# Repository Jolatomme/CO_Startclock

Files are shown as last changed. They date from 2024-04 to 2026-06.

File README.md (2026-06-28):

# Orienteering Start Clock synchronized to DCF77



Equity in sport is a key point during competition. In orienteering, equity is not guaranteed — start time differs per category and per racer. The start clock has no synchronization with the finish clock (managed by the punching system). Two unsynchronized clocks will drift and introduce uncertainty in effective race time. This project solves that problem by keeping the start clock synchronized to the absolute time delivered by the DCF77 signal.

More details on the [project Wiki](https://github.com/Jolatomme/CO_Startclock/wiki).

## Features

- Synchronizes to DCF77 time signal (German longwave, 77.5 kHz)
- Falls back to internal RTC when DCF77 signal is unavailable
- Real-time display on MAX7219 LED dot matrix (64x8)
- Automatic DST (summer/winter time) handling
- Built on MicroPython for rapid prototyping

## Hardware Requirements

| Component | Description |
|---|---|
| Microcontroller | STM32 Nucleo-64 board (see [supported boards](https://github.com/Jolatomme/CO_Startclock/wiki#micro-controller-platform)) |
| DCF77 receiver | Standard DCF77 module with antenna (e.g., DCF77-1, Hama, etc.) |
| Display | MAX7219-based 8x8 LED dot matrix, 8 modules chained (64x8) |
| Power | USB or external 5V supply |

## Pin Connections

| Nucleo Pin | Connection |
|---|---|
| D4 | DCF77 receiver TCO (time signal output) |
| D7 | MAX7219 CS (chip select) |
| SPI2 SCK | MAX7219 CLK |
| SPI2 MOSI | MAX7219 DIN |
| 3.3V / 5V | DCF77 receiver VCC |
| GND | Common ground |

## Getting Started

### 1. Install MicroPython

Download the latest MicroPython firmware for your board from [micropython.org](https://micropython.org/download/) and flash it using the STM32 Cube Programmer or DFU mode.

### 2. Upload the firmware

```bash
# Using ampy
ampy --port COM3 put boot.py
ampy --port COM3 put main.py
ampy --port COM3 put dcf77.py
ampy --port COM3 put max7219.py

# Or using rshell
rshell -p COM3 cp *.py /pyboard/
```

### 3. Wire the components

Refer to the [Fritzing layout](Fritzing/CO_Clock.fzz) or the [KiCad schematics](StartClock/StartClock.kicad_sch) for detailed wiring.

### 4. Power on

The clock will synchronize with DCF77 and display the current time. The onboard LED blinks once per second and stays on during the last 10 seconds of each minute.

## Project Structure

```
├── nucleo_flash/          # MicroPython firmware
│   ├── boot.py            # Boot configuration
│   ├── main.py            # Main application (async RTC + display)
│   ├── dcf77.py           # DCF77 signal decoder
│   ├── max7219.py         # MAX7219 LED matrix driver
│   └── ds18x20.py         # DS18X20 temperature sensor driver
├── StartClock/            # KiCad hardware design
│   ├── StartClock.kicad_sch   # Schematic
│   ├── StartClock.kicad_pcb   # PCB layout
│   └── StartClock.kicad_pro   # Project file
├── Fritzing/              # Breadboard layout
│   └── CO_Clock.fzz
├── Img/                   # Images
├── README.md
└── LICENSE                # MIT
```

## Project example on a single-sided stripboard

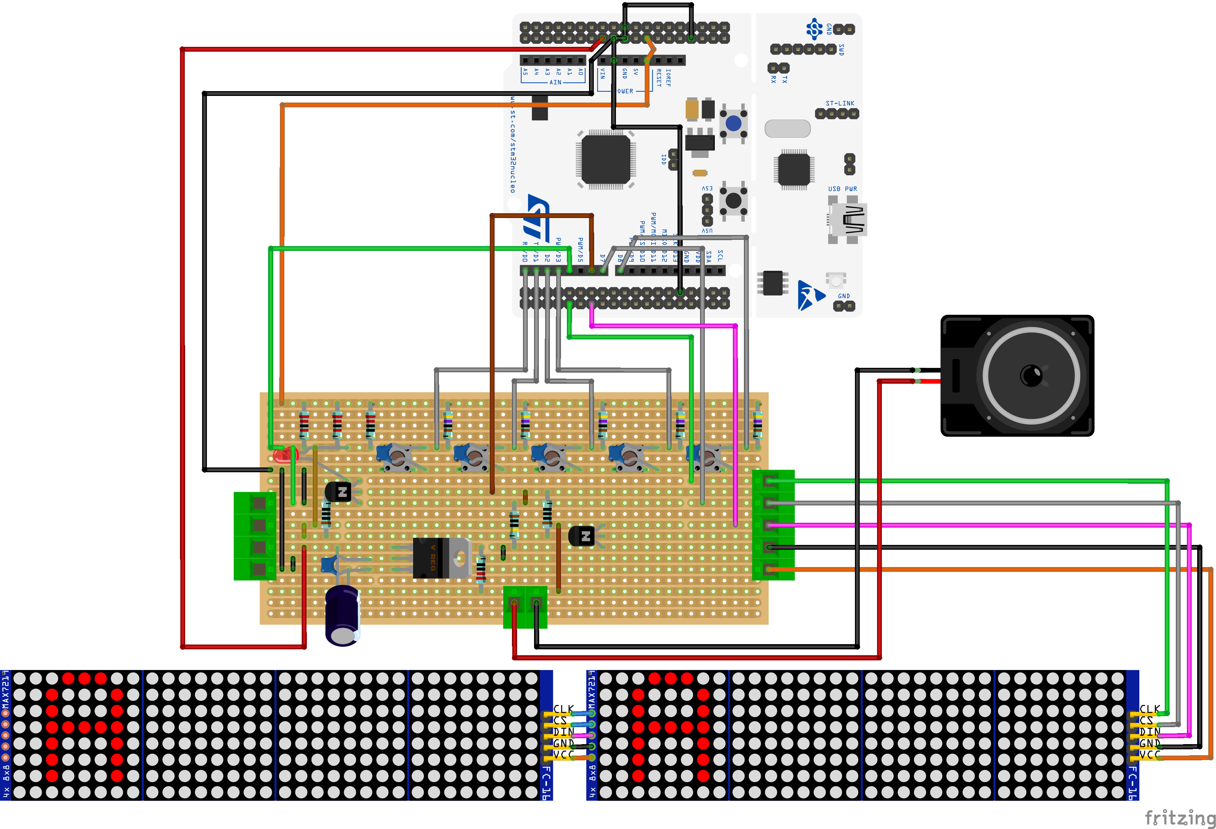
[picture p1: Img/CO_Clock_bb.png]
Realization


## License

This project is licensed under the [MIT License](LICENSE).

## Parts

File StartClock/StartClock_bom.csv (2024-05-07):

Reference | Value | Footprint | Qty | DNP | Ref mouser | Description
C1,C2,C3,C5,C6,C7,C11,C12 | 100n | Capacitor_SMD:C_0805_2012Metric_Pad1.18x1.45mm_HandSolder | 8 |  | https://www.mouser.fr/ProductDetail/KEMET/C0805C104K6RACTU?qs=NrXEK%2Fuukt5je6JkV2NA6Q%3D%3D | Unpolarized capacitor
C4,C13,C14 | 4.7u | Capacitor_SMD:C_0805_2012Metric_Pad1.18x1.45mm_HandSolder | 3 |  | https://www.mouser.fr/ProductDetail/Murata-Electronics/GRM21BZ7YA475KE15L?qs=Ey7%2FXF42M3dwsQijVSe80A%3D%3D | Unpolarized capacitor
C8 | 0.047u | Capacitor_SMD:C_0805_2012Metric_Pad1.18x1.45mm_HandSolder | 1 |  | https://www.mouser.fr/ProductDetail/KYOCERA-AVX/08053C473KAT4A?qs=OgzxwkGQ6NJ%2FkRAYg4QbYg%3D%3D | Unpolarized capacitor
C9 | 220u | Capacitor_THT:CP_Radial_D10.0mm_P5.00mm | 1 |  | None: in Stock | Polarized capacitor
C10 | 10u | Capacitor_SMD:C_0805_2012Metric_Pad1.18x1.45mm_HandSolder | 1 |  | https://www.mouser.fr/ProductDetail/Murata-Electronics/GRM21BZ71E106KE15K?qs=Ey7%2FXF42M3ceEkXCU194qQ%3D%3D | Unpolarized capacitor
D1 | LED | LED_SMD:LED_0805_2012Metric_Pad1.15x1.40mm_HandSolder | 1 |  | https://www.mouser.fr/ProductDetail/Wurth-Elektronik/150080SS75000?qs=LlUlMxKIyB2zzpiaOzrUdw%3D%3D | Light emitting diode
J1 | Screw_Terminal_01x05 | TerminalBlock_Phoenix:TerminalBlock_Phoenix_MPT-0,5-5-2.54_1x05_P2.54mm_Horizontal | 1 |  | https://www.mouser.fr/ProductDetail/Wurth-Elektronik/691210910005?qs=sPbYRqrBIVmsC84njkCQMg%3D%3D | Generic screw terminal, single row, 01x05, script generated (kicad-library-utils/schlib/autogen/connector/)
J2,J3,J4 | Screw_Terminal_01x02 | TerminalBlock_Phoenix:TerminalBlock_Phoenix_MPT-0,5-2-2.54_1x02_P2.54mm_Horizontal | 3 |  | https://www.mouser.fr/ProductDetail/Wurth-Elektronik/691210910002?qs=sPbYRqrBIVlpmUgpxfjjUA%3D%3D | Generic screw terminal, single row, 01x02, script generated (kicad-library-utils/schlib/autogen/connector/)
J5 | Screw_Terminal_01x04 | TerminalBlock_Phoenix:TerminalBlock_Phoenix_MPT-0,5-4-2.54_1x04_P2.54mm_Horizontal | 1 |  | https://www.mouser.fr/ProductDetail/Wurth-Elektronik/691210910004?qs=sPbYRqrBIVlxffWXw70IkA%3D%3D | Generic screw terminal, single row, 01x04, script generated (kicad-library-utils/schlib/autogen/connector/)
Q1,Q2 | 2STR1160 | Package_TO_SOT_SMD:TSOT-23 | 2 |  | None: in Stock | NPN transistor, base/emitter/collector
R1,R10 | 100 | Resistor_SMD:R_0805_2012Metric_Pad1.20x1.40mm_HandSolder | 2 |  | https://www.mouser.fr/ProductDetail/YAGEO/RT0805DRD07100RL?qs=%2Ff7pOCXLR5eK3aDJ3OLj3w%3D%3D | Resistor, US symbol
R2,R12 | 220 | -- valeurs mixtées -- | 2 |  | -- valeurs mixtées -- | Resistor, US symbol
R3,R9 | 22k | Resistor_SMD:R_0805_2012Metric_Pad1.20x1.40mm_HandSolder | 2 |  | https://www.mouser.fr/ProductDetail/YAGEO/RT0805FRE1322KL?qs=1mbolxNpo8eWV%252BfmE3nyzw%3D%3D | Resistor, US symbol
R4,R5,R6,R8,R11 | 4.7k | Resistor_SMD:R_0805_2012Metric_Pad1.20x1.40mm_HandSolder | 5 |  | https://www.mouser.fr/ProductDetail/YAGEO/RC0805FR-074K7L?qs=VLOqbHBAO5cYXbrd7RTmuQ%3D%3D | Resistor, US symbol
R7 | 1Meg | Resistor_SMD:R_0805_2012Metric_Pad1.20x1.40mm_HandSolder | 1 |  | https://www.mouser.fr/ProductDetail/YAGEO/RT0805FRE101ML?qs=F5EMLAvA7ICcBycWGMkoRg%3D%3D | Resistor, US symbol
R13 | 9.1k | Resistor_SMD:R_0805_2012Metric_Pad1.20x1.40mm_HandSolder | 1 |  | https://www.mouser.fr/ProductDetail/YAGEO/RT0805FRE079K1L?qs=yNCrj0CQcyLO9GcBQGw%2FWw%3D%3D | Resistor, US symbol
R14,R16 | 1.2k | Resistor_SMD:R_0805_2012Metric_Pad1.20x1.40mm_HandSolder | 2 |  | https://www.mouser.fr/ProductDetail/YAGEO/RT0805FRE071K2L?qs=Of9BA0M78V%2FOQKObZjZlOg%3D%3D | Resistor, US symbol
R15 | 10 | Resistor_SMD:R_0805_2012Metric_Pad1.20x1.40mm_HandSolder | 1 |  | https://www.mouser.fr/ProductDetail/YAGEO/RT0805FRE1310RL?qs=1mbolxNpo8cxANW8i7GXPg%3D%3D | Resistor, US symbol
SW1,SW2,SW3,SW4,SW6 | SW_Omron_B3FS | Button_Switch_SMD:SW_SPST_Omron_B3FS-101xP | 5 |  | https://www.mouser.fr/ProductDetail/Omron-Electronics/B3FS-1012P?qs=1tDaWCEHQQ7mwfTJVAKWQA%3D%3D | Omron B3FS 6x6mm single pole normally-open tactile switch
U1 | CO StartClock | Nucleo_64:ST_Morpho_Connector_64_NOHOLES_TOP | 1 |  | None: in Stock | Nucleo 64 Development Board with STM32L152RE
U2 | LM78M05_TO252 | Package_TO_SOT_SMD:TO-252-2 | 1 |  | https://www.mouser.fr/ProductDetail/STMicroelectronics/L7805CDT-TR?qs=gq%2F78KzUDX67VndS%2FbSB4Q%3D%3D | Positive 500mA 35V Linear Regulator, Fixed Output 5V, TO-252 (D-PAK)
U3 | LM386 | Package_SO:SOIC-8_3.9x4.9mm_P1.27mm | 1 |  | https://www.mouser.fr/ProductDetail/Texas-Instruments/LM386MX-1-NOPB?qs=QbsRYf82W3FIdJRa%252BlgeNQ%3D%3D | Low Voltage Audio Power Amplifier, DIP-8/SOIC-8/SSOP-8

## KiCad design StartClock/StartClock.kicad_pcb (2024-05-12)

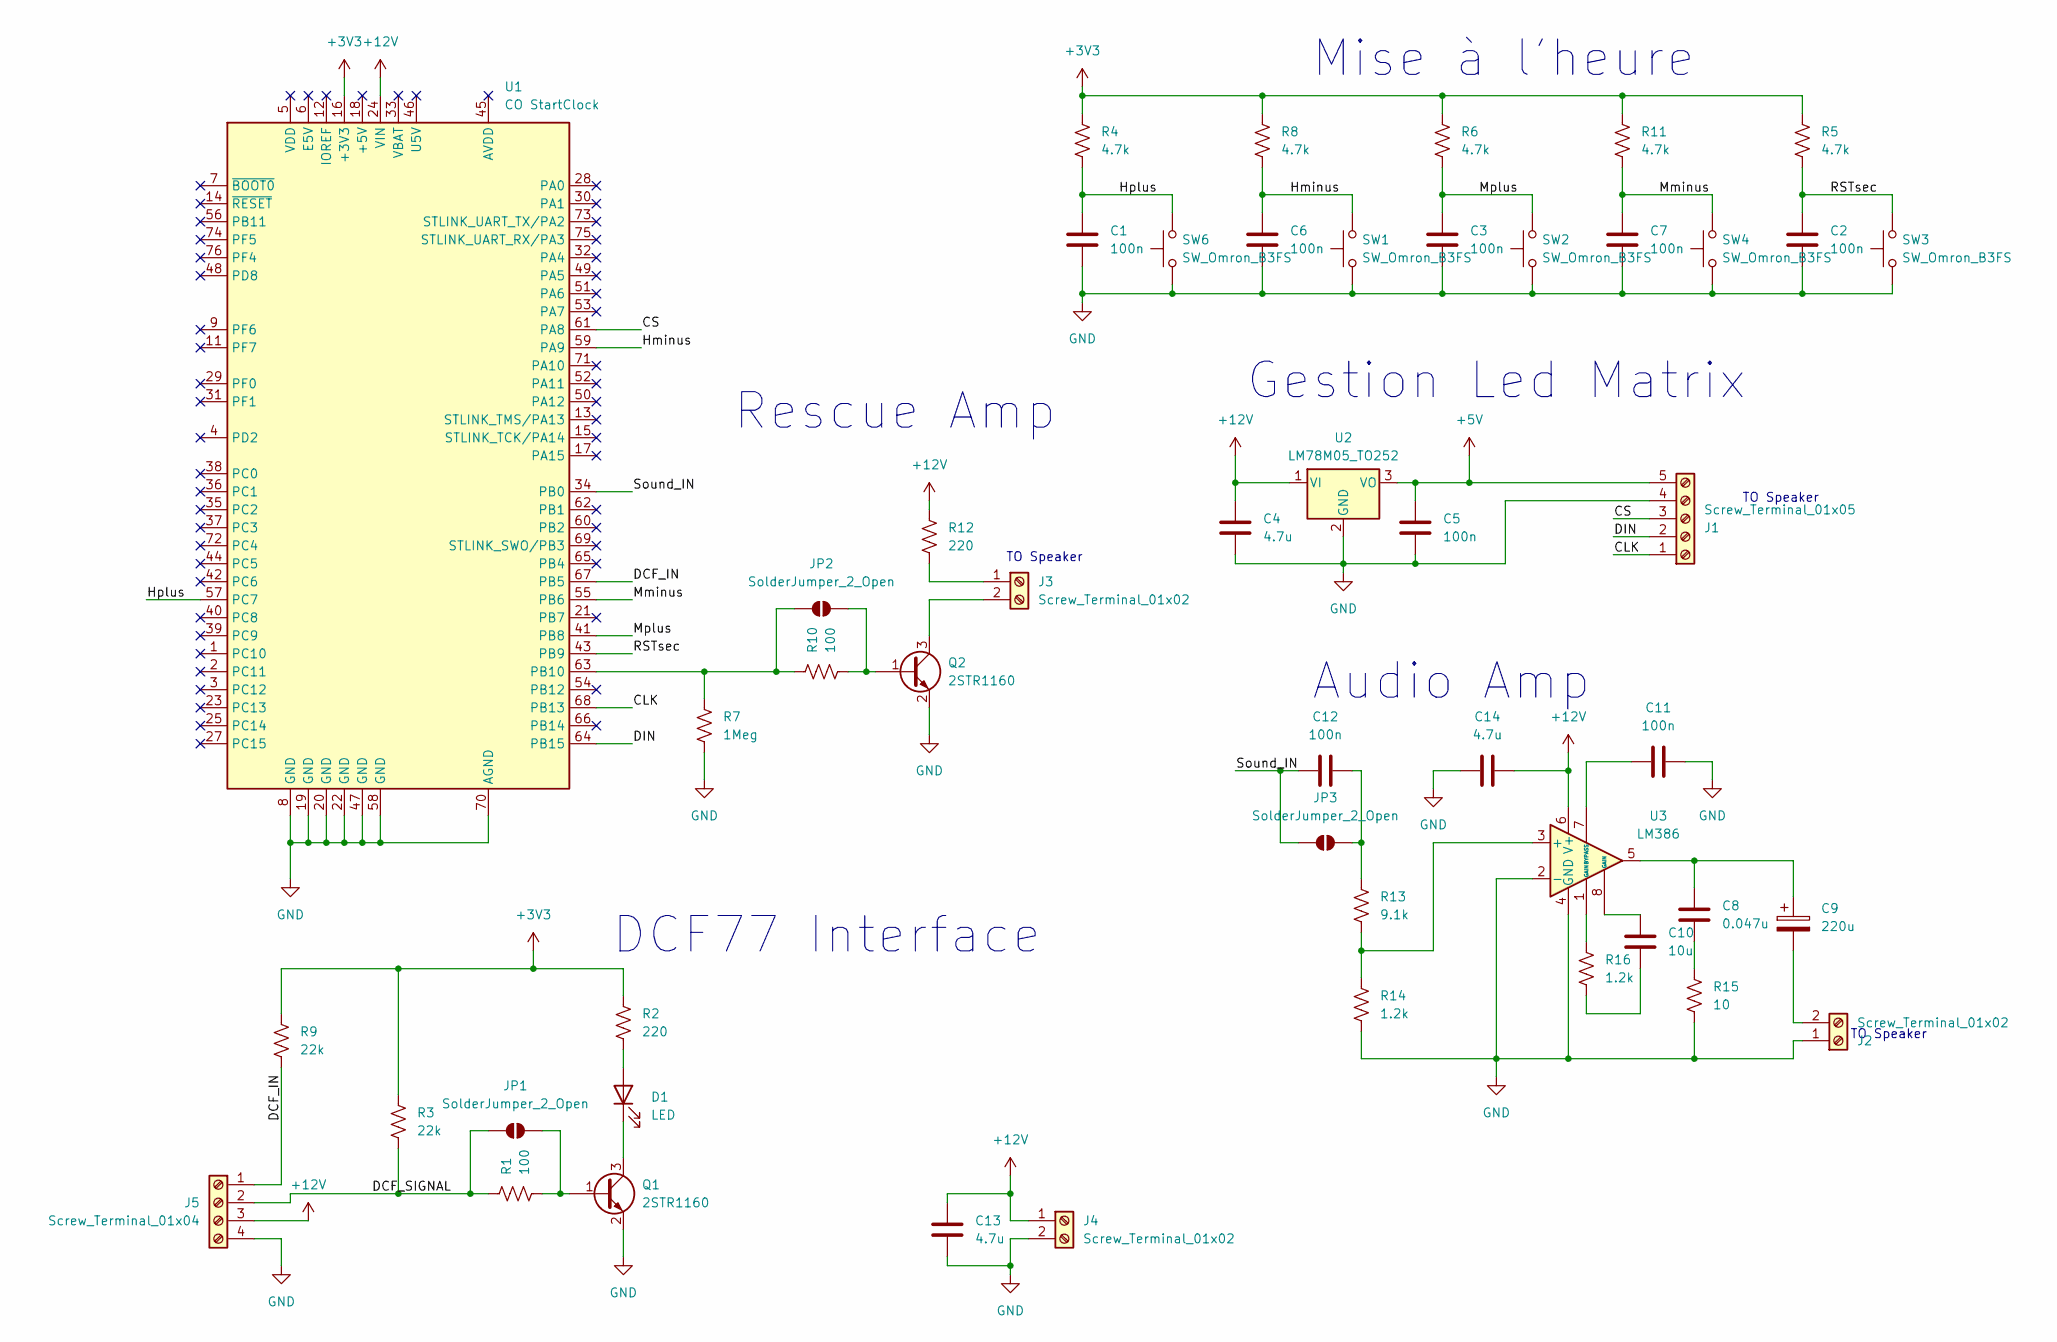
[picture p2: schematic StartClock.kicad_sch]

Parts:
C1, C2, C3, C5, C6, C7, C11, C12: 100n; C_0805_2012Metric_Pad1.18x1.45mm_HandSolder
C4, C13, C14: 4.7u; C_0805_2012Metric_Pad1.18x1.45mm_HandSolder
C8: 0.047u; C_0805_2012Metric_Pad1.18x1.45mm_HandSolder
C9: 220u; CP_Radial_D10.0mm_P5.00mm
C10: 10u; C_0805_2012Metric_Pad1.18x1.45mm_HandSolder
D1: LED; LED_0805_2012Metric_Pad1.15x1.40mm_HandSolder
J1: Screw_Terminal_01x05; TerminalBlock_Phoenix_MPT-0,5-5-2.54_1x05_P2.54mm_Horizontal
J2, J3, J4: Screw_Terminal_01x02; TerminalBlock_Phoenix_MPT-0,5-2-2.54_1x02_P2.54mm_Horizontal
J5: Screw_Terminal_01x04; TerminalBlock_Phoenix_MPT-0,5-4-2.54_1x04_P2.54mm_Horizontal
JP1, JP2, JP3: SolderJumper_2_Open; SolderJumper-TrianglePad1.0x1.5mm
Q1, Q2: 2STR1160; TSOT-23
R1, R10: 100; R_0805_2012Metric_Pad1.20x1.40mm_HandSolder
R2: 220; R_0805_2012Metric_Pad1.20x1.40mm_HandSolder
R3, R9: 22k; R_0805_2012Metric_Pad1.20x1.40mm_HandSolder
R4, R5, R6, R8, R11: 4.7k; R_0805_2012Metric_Pad1.20x1.40mm_HandSolder
R7: 1Meg; R_0805_2012Metric_Pad1.20x1.40mm_HandSolder
R12: 220; R_2512_6332Metric
R13: 9.1k; R_0805_2012Metric_Pad1.20x1.40mm_HandSolder
R14, R16: 1.2k; R_0805_2012Metric_Pad1.20x1.40mm_HandSolder
R15: 10; R_0805_2012Metric_Pad1.20x1.40mm_HandSolder
SW1, SW2, SW3, SW4, SW6: SW_Omron_B3FS; SW_SPST_Omron_B3FS-101xP
U1: CO StartClock; ST_Morpho_Connector_64_NOHOLES_TOP
U2: LM78M05_TO252; TO-252-2
U3: LM386; SOIC-8_3.9x4.9mm_P1.27mm

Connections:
+3V3: R2.2, R3.2, R4.2, R5.2, R6.2, R8.2, R9.2, R11.2, U1.16 (+3V3)
+5V: C5.1, J1.5, U2.3 (VO)
+12V: C4.1, C13.1, C14.1, J4.1, J5.3, R12.2, U1.24 (VIN), U2.1 (VI), U3.6 (V+)
/CLK: J1.1, U1.68 (PB13)
/CS: J1.3, U1.61 (PA8)
/DCF_IN: J5.1, R9.1, U1.67 (PB5)
/DCF_SIGNAL: J5.2, JP1.1 (A), R1.1, R3.1
/DIN: J1.2, U1.64 (PB15)
/Hminus: C6.1, R8.1, SW1.2, U1.59 (PA9)
/Hplus: C1.1, R4.1, SW6.2, U1.57 (PC7)
/Mminus: C7.1, R11.1, SW4.2, U1.55 (PB6)
/Mplus: C3.1, R6.1, SW2.2, U1.41 (PB8)
/RSTsec: C2.1, R5.1, SW3.2, U1.43 (PB9)
/Sound_IN: C12.1, JP3.1 (A), U1.34 (PB0)
GND: C1.2, C2.2, C3.2, C4.2, C5.2, C6.2, C7.2, C11.2, C13.2, C14.2, J1.4, J2.1, J4.2, J5.4, Q1.2 (E), Q2.2 (E), R7.1, R14.1, R15.1, SW1.1, SW2.1, SW3.1, SW4.1, SW6.1, U1.8 (GND), U1.19 (GND), U1.20 (GND), U1.22 (GND), U1.47 (GND), U1.58 (GND), U1.70 (AGND), U2.2 (GND), U3.2 (-), U3.4 (GND)
unnamed: C8.1, C9.1, U3.5
unnamed: C8.2, R15.2
unnamed: C10.1, U3.8 (GAIN)
unnamed: C10.2, R16.1
unnamed: D1.2 (A), R2.1
unnamed: D1.1 (K), Q1.3 (C)
unnamed: C9.2, J2.2
unnamed: J3.1, R12.1
unnamed: J3.2, Q2.3 (C)
unnamed: JP1.2 (B), Q1.1 (B), R1.2
unnamed: JP2.1 (A), R7.2, R10.1, U1.63 (PB10)
unnamed: JP2.2 (B), Q2.1 (B), R10.2
unnamed: C12.2, JP3.2 (B), R13.2
unnamed: R16.2, U3.1 (GAIN)
unnamed: R13.1, R14.2, U3.3 (+)
unnamed: C11.1, U3.7 (BYPASS)

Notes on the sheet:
TO Speaker
Audio Amp
Rescue Amp
DCF77 Interface
Mise à l'heure
Gestion Led Matrix

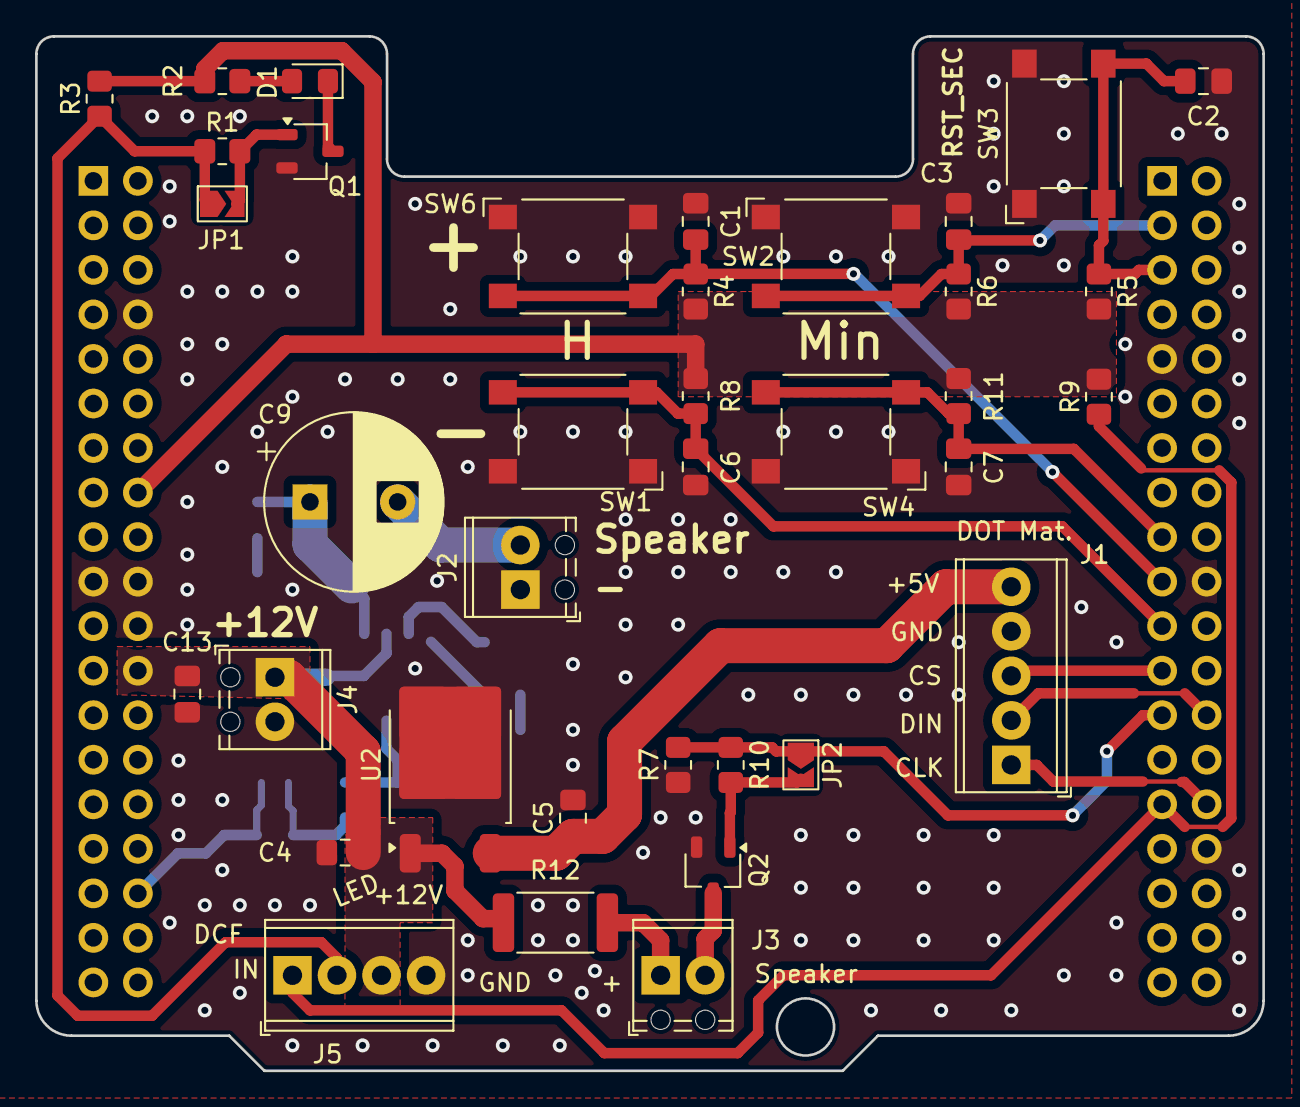
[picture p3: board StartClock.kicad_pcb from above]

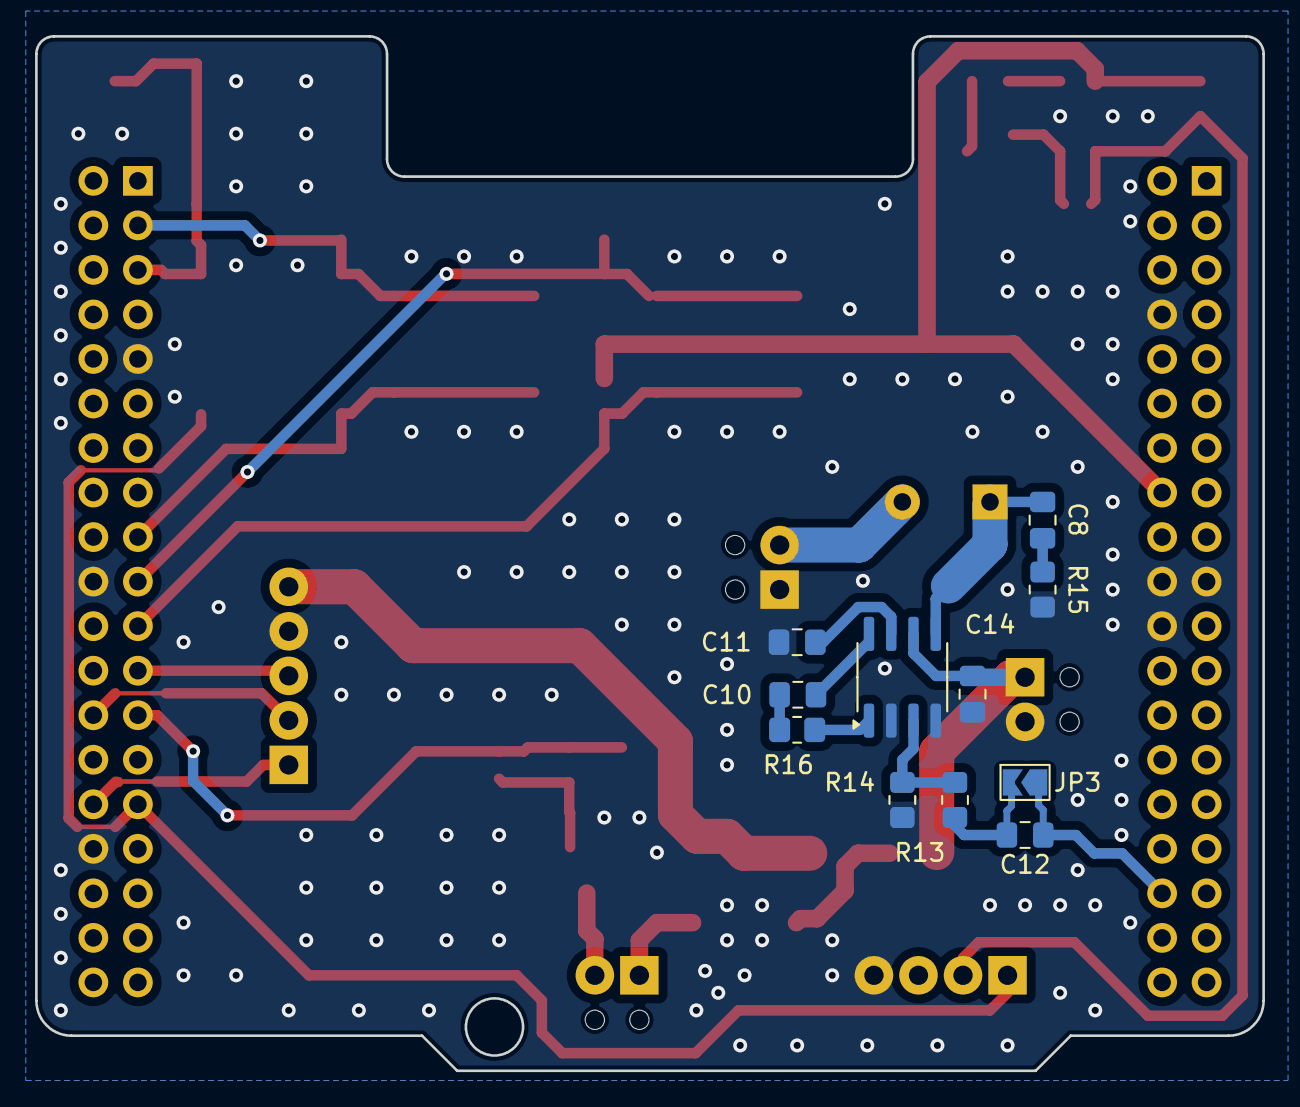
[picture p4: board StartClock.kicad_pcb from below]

Board: 2 copper layers, 70.0 x 59.0 mm, 49 parts (11 on the bottom side), 31 nets.

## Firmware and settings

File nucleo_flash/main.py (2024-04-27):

# main.py -- put your code here!
# pyb module already imported
import micropython
import asyncio
from machine import Pin, SPI
import max7219
import dcf77

# buffer for interrupt
micropython.alloc_emergency_exception_buf(100)

# asynchronous interrupt from RTC
ITRtcTSF = asyncio.ThreadSafeFlag()
# asynchronous interrupt from DCF
ITDcfTSF = asyncio.ThreadSafeFlag()

class Rtc(object):
    ''' RTC based on interrupts
    '''
    def __init__(self, rtc=None, timeout=10):
        self.rtc = rtc
        self.rtc.wakeup(timeout, self.cb)

    def cb(self, t):
        ''' RTC callback
            Datetime structure [4] : H.; [5] : min.; [6] : sec.
        '''
        global ITRtcTSF
        ITRtcTSF.set()

    def get_time(self):
        ''' Return RTC time
        '''
        return self.rtc.datetime()[4:7]

    def set_datetime(self, datetime):
        ''' Set RTC time
        '''
        return self.rtc.datetime(datetime)


class Dcf(object):
    ''' Dcf based on interrupts
    '''
    def __init__(self, dcf=None):
        self.dcf = dcf
        self.start()
        self.dcf.irq([dcf.IRQ_MINUTE], self.cb)

    def cb(self):
        ''' DCF callback
        '''
        global ITDcfTSF
        ITDcfTSF.set()

    def GETInfos(self):
        return self.dcf.get_Infos()

    def GETLastSignal(self):
        return self.dcf.get_LastSignal()

    def GETDateTime(self):
        return self.dcf.get_DateTime()

    def GETLastPulseLength(self):
        return self.dcf.last_pulse

    def start(self):
        ''' Start DCF
        '''
        self.dcf.start()

    def stop(self):
        ''' Stop DCF
        '''
        self.dcf.stop()


class MatrixDisp(object):
    ''' Display using MAX7219
    '''
    def __init__(self, spi=None, CSpin=None, Xdim=64, Ydim=8):
        self.screen = max7219.Max7219(Xdim, Ydim, spi, CSpin)
        self.clear()
        self.brightness(0)

    def clear(self):
        ''' Clearing display
        '''
        self.screen.fill(0)
        self.screen.show()

    def write(self, txt='', PosX=0, PosY=0):
        ''' Display string on screen
        '''
        self.screen.fill(0)
        self.screen.text(txt, PosX, PosY, 1)
        self.screen.show()

    def brightness(self, level):
        ''' Control screen brightness
            0: min; 15: MAX
        '''
        self.screen.brightness(level)


################
# Led Init
################
# led definition usefull for debug
led = pyb.LED(1)

################
# Matrix Display
################
# Using SPI 2 for easy PIN wiring on Nucleo 64
# and chip select PIN D7
screen = MatrixDisp(SPI(2, baudrate=10000000), Pin('D7'))

################
# RTC Init
################
rtc = Rtc(pyb.RTC())

################
# DCF77
################
dcf = Dcf(dcf77.dcf77(Pin('D4')))

prev_sec = -1
updating_display = False

async def DispUpdate():
    global prev_sec
    global updating_display
    updating_display = True
    h_, min_, sec_ = rtc.get_time()
    if sec_ != prev_sec:
        h_txt = '{0:0=2d}:{1:0=2d}:{2:0=2d}'.format(h_, min_, sec_)
        screen.write(h_txt)
        if sec_ in (50, 55, 56, 57, 58, 59):
            led.on()
            await asyncio.sleep_ms(200)
            led.off()
        elif sec_ == 0:
            led.on()
            await asyncio.sleep_ms(500)
            led.off()
        prev_sec = sec_
    updating_display = False

async def RTCResync():
    while True:
        await ITDcfTSF.wait()
        DCFdatetime = dcf.GETDateTime()
        rtc.set_datetime(DCFdatetime)

async def main():
    asyncio.create_task(RTCResync())
    while True:
        await ITRtcTSF.wait()
        if updating_display == False:
            asyncio.create_task(DispUpdate())

asyncio.run(main())

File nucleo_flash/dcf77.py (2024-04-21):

'''
2023-11-17  -   First release
2024-01-20  -   - Bugfix for date decoding and parity check
                - Disable and enable debug messages with separate function
'''

import utime
from machine import Pin, Timer

class dcf77:
    # Constants for the irq handler
    IRQ_MINUTE = 0
    IRQ_HOUR = 1
    IRQ_DAY = 2
    IRQ_MONTH = 3
    IRQ_YEAR = 4
    IRQ_DST = 5

    def __init__ (self, tco_pin: Pin,
                  false_time: list[int] = [50, 130],
                  true_time: list[int] = [150, 230],
                  pause_time: list[int] = [1700, 2500]):
        '''
        - ``tco_pin``: Pin object of the TCO pin
        - ``false_time``: Minimum/Maximum impulse width for a FALSE signal
        - ``true_time``: Minimum/Maximum impulse width for a TRUE signal
        - ``pause_time``: Minimum/Maximum pause to recognize tick 59
        '''
        self.FALSE_TIME = false_time
        self.TRUE_TIME = true_time
        self.TICK59_TIME = pause_time
        self.TCO = tco_pin
        self.DEBUG = False
        self.TIMEOUT_TIME = self.TICK59_TIME[1] + 1000

        self.irq_start = 0  #Starttime of the interrupt
        self.irq_last = 0   #Time of last interrupt
        self.last_pulse = 0 #Length of last pulse
        self.timer_timeout = Timer(-1) #Timer for timeout handling

        self.found59 = False    #Tick59 was found
        self.tick = 0           #Actual tick
        self.signal = []        #Actual received signal
        self.signal_last = []   #Last received signal
        self.valid = False      #Signal is valid
        self.datetime = [0, 0, 0, 0, 0, 0, 0, 0]
        self.datetime_last = [0, 0, 0, 0, 0, 0, 0, 0]
        self.dst_changed = False

        # Init TCO pin
        self.TCO.init(mode=Pin.IN, pull=Pin.PULL_UP)

    # Function to print debug messages
    def __print(self, *val):
        if self.DEBUG:
            text = ''
            for v in range(len(val)):
                text += str(val[v])

            print("DCF77: ", text)

    # Interrupt handler for the DCF IRQ
    def __handler_interrupt(self, pin):
        self.__run()

    # Interrupt hanlder for the timeout timer
    def __timeout_callback(self, timer):
        self.found59 = False
        self.valid = False
        self.tick = 0
        self.signal.clear()
        self.__print("Signal timeout - Start new scanning for tick 59")

    # Main function. Called from the interrupt handler
    def __run(self):
        # Starting the timeout timer
        self.timer_timeout.init(mode=Timer.ONE_SHOT, period=self.TIMEOUT_TIME, callback=self.__timeout_callback)

        # If the last edge was detected between min/max TICK59_TIME
        # we have found the beginning of the telegram
        if utime.ticks_diff(utime.ticks_ms(), self.irq_last) > self.TICK59_TIME[0] \
            and utime.ticks_diff(utime.ticks_ms(), self.irq_last) < self.TICK59_TIME[1]:
            if not self.found59:
                self.__print("Found Tick 59")
                self.tick = 0
                self.found59 = True

        # Saving the actual time for comparsion
        self.irq_last = utime.ticks_ms()
        # If the signal from the DCF module is low
        # we save the time
        if not self.TCO.value():
            self.irq_start = utime.ticks_ms()
        else:
            # The signal from the DCF module is high
            # Calculate the pulse length
            diff = utime.ticks_diff(utime.ticks_ms(), self.irq_start)
            self.last_pulse = diff
            val = 2

            # Is the pulse a 0 or 1?
            if diff >= self.FALSE_TIME[0] and diff <= self.FALSE_TIME[1]:
                val = 0
            elif diff >= self.TRUE_TIME[0] and diff <= self.TRUE_TIME[1]:
                val = 1
            else:
                self.__print("Wrong pulse width - Start new scanning for tick 59")
                self.found59 = False
                self.signal.clear()

            # If the beginning of the telegram was found let count the ticks and save the values
            if self.found59:
                # self.__print("Tick: ", self.tick, " - ", val)
                self.signal.append(val)
                self.irq_start = 0
                self.tick += 1

                # If we have tick 59 the telegram is completed
                # Copy the data to another list and clear the source list
                if self.tick > 58:
                    self.signal_last = self.signal.copy()
                    self.signal.clear()
                    self.tick = 0

                # If tick is 1 end the saved signal list is not empty
                # we have a valid telegram
                if self.tick == 1:
                    if len(self.signal_last) > 0:
                        self.valid = True
                        self.__decode()
                        self.__custom_irq()
                        self.__print("Last Transmission: ", self.signal_last)

    # Function to decoding the time informations
    def __decode_time(self, time, check_parity):
        vals = [1, 2, 4, 8, 10, 20, 40, 80] # Values for the bit positions
        sum = 0 # Counter variable
        parity_check = 0 # Counter variable for the parity check

        # If check_parity is True the last value in the list is the parity
        # so we should not count this value
        end = len(time)
        if check_parity:
            end -= 1

        # Counting the time or date    
        for t in range(end):
            if time[t]:
                sum += vals[t]
                parity_check += 1

        # Checking parity
        # If a even number of bits was TRUE the parity
        # has to be FALSE
        if check_parity:
            if ( parity_check % 2 ) == 0:
                if time[-1]:
                    self.valid = False
                    self.__print("Parity is not correct")
                    return 999
        
        return sum
    
    # Function to decoding the date informations
    def __decode_date(self, date, check_parity=True):
        vals = [1, 2, 4, 8, 10, 20, 40, 80] # Values for the bit positions
        parity_check = 0 # Counter variable for the parity check

        # Checking parity
        # If a even number of bits was TRUE the parity
        # has to be FALSE
        if check_parity:
            for t in range(len(date) - 1):
                if date[t]:
                    parity_check += 1

            if ( parity_check % 2 ) == 0:
                if date[-1]:
                    self.valid = False
                    self.__print("Parity is not correct")
                    return [999, 999, 999, 999]
            
        # Decoding Day of month
        DayOfMonth = 0
        for v, b in enumerate(date[0:6]):
            if b:
                DayOfMonth += vals[v]

        # Decoding the weekday
        Weekday = 0
        for v, b in enumerate(date[6:9]):
            if b:
                Weekday += vals[v]
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

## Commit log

2024-05-05 Added Clock Schematics done with Fritzing
    [CO_Clock.fzz]
2024-05-07 First version for Nucelo Shield with KiCad
    [CO_Clock.fzz, StartClock.kicad_pcb, StartClock.kicad_sch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]
2024-05-07 Components updates after Mouser ordering few parts changed due to unavailability
    [StartClock.kicad_pcb, StartClock.kicad_sch, StartClock_bom.csv]
2024-05-07 After Aisler PCB order
    [StartClock.kicad_pcb]
2024-05-12 Added extra filtering
2024-05-12 Aisler number removed for sharing
    [StartClock.kicad_pcb]
